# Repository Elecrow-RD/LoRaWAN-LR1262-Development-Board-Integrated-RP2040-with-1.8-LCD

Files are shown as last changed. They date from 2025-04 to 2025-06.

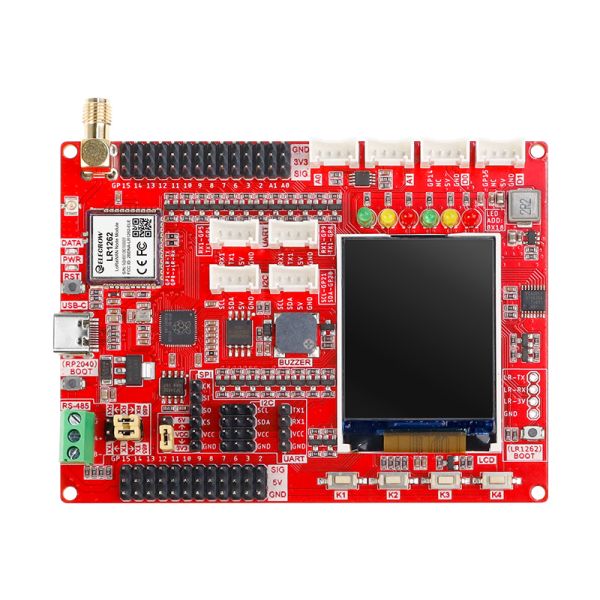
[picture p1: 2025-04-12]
crt01267d_lora_lr1262_dev_board_1.jpg

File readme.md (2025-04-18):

### 1, Product picture

crt01267d_lora_lr1262_dev_board_1

### 2, Product version number

| | Hardware | Software | Remark |
| ---- | --- | --- | --- |
| 1 | V1.0 | V1.0 | latest |

### 3, product information

#### Display Module Specifications

**GPIO Pin Definition**

| RP2040 | LR1262 Development Board | | |
| --- | --- | --- | --- |
| GPIO0  | LR1262-RXD | GPIO15 | GPIO15/ Crowtail-D1 |
| GPIO1  | LR1262-TXD | GPIO16 | LCD-DC |
| GPIO2  | GPIO2 | GPIO17 | LCD-CS |
| GPIO3  | GPIO3 | GPIO18 | LCD-SCK |
| GPIO4  | Crowtail-UART1-TXD | GPIO19 | LCD-DIN |
| GPIO5  | Crowtail-UART1-RXD | GPIO20 | I2C0-SDA0/Crowtail-I2C-SDA/PCA9555-SDA  |
| GPIO6  | GPIO6 | GPIO21 | I2C0-SCL0/Crowtail-I2C-SCL/ PCA9555-SCL |
| GPIO7  | GPIO7 | GPIO22 | LCD-RST |
| GPIO8  | GPIO8/UART1-TX1/Crowtail-UART1-TX1/485TX | GPIO23 | LCD-BLK |
| GPIO9  | GPIO9/UART1-RX1Crowtail-UART1-RX1/485RX  | GPIO24 | 485-EN |
| GPIO10 | GPIO10/SPI1-SCK | GPIO25 | DATA |
| GPIO11 | GPIO11/SPI1-MOSI | GPIO26 | A0/ Crowtail-A0 |
| GPIO12 | GPIO12/SPI1-MISO | GPIO27 | A1/ Crowtail-A1 |
| GPIO13 | GPIO13/SPI1-CS | GPIO28 | BUZZER |
| GPIO14 | GPIO14/ Crowtail-D0 | GPIO29 | ADC-KEY |

## Feature

- Uses RP2040 as the main controller, with two 32-bit ARM Cortex M0+ processor cores (dual-core) ,and provides more powerful performance
- Integrates the LR1262 module supports the 868/915MHz frequency band and AT command control
- Abundant external interface resources, compatible with Crowtail series modules and other commonly interface modules on the market
- Integrates commonly used functionslike buzzer, LED light, LCD display and custom button, making it more concise and convenient when creating projects
- Onboard 1.8-inch 128*160 SPI-TFT-LCD, ST7735S driver chip
- Compatible with Arduino/Micropython, easy to carry out different projects.

## Specification

| Main Chip | Raspberry Pi chip RP2040, built-in 264KB SRAM, onboard 4MB Flash |
| --- | --- |
| Processor | Dual Core Arm Cortex-M0+ @ 133MHz |
| LR1262 Supports frequency band | 803MHZ-930MHZ |
| LR1262 Support Interface | External antenna, SMA interface or IPEX first generation interface |
| LCD Display | Onboard 1.8-inch 128*160SPI-TFT-LCD |
| LCD Resolution | 128*160 |
| LCD Driver | ST7735S (4-wire SPI) |
| Development environment | Arduino/Micropython |
| Interface | 1x RS485 communication interface,8x 5V Crowtail interfaces (2x analog interfaces, 2xdigital interfaces, 2xUART interfaces, 2xIIC interfaces)12x 5V universal pin header IO interfaces14x 3.3V universal pin header IO interfaces1x 3.3V/5V switchable SPI interface1x 3.3V/5V switchable UART interface3x 3.3V/5V switchable IIC interfaces |
| Buttons and functions | 1x passive buzzer,4x user-defined buttons,6x programmable LEDs |
| Working input voltage | USB 5V-1A |
| Operating temperature | -10°C ~ 65°C |
| Dimensions | 102mm(L)x76.5mm(W) |

### 4,Quick Start

##### Arduino IDE starts

STEP1 Configure controller board&communication port
On top of the Arduino IDE, click “Tools>Board>” and select “*Rasperry Pi RP2040 Boards*” from the available options
Lora RA-08H 1 7.png
STEP2 Select the COM port that indicates Rasperry Pi RP2040 Boards. Please note that the actual numbers after the “COM” word will vary from computer to computer, so they could be different from the ones shown in the figure.

### 6,Folder structure.

|--Datasheet: Includes datasheets for components used in the project, providing detailed specifications, electrical characteristics, and pin configurations.

|--Eagle_SCH&PCB: Contains **Eagle CAD** schematic (`.sch`) and PCB layout (`.brd`) files. These are used for circuit design and PCB manufacturing.

|--example: Provides example code and projects to demonstrate how to use the hardware and libraries. These examples help users get started quickly.

|--factory_firmware: Stores pre-compiled factory firmware that can be directly flashed onto the device. This ensures the device runs the default functionality.

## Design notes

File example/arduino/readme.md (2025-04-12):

**Arduino**: This folder contains sample programs for the Arduino platform, which is known for its ease of use and versatility in creating interactive electronic projects.

Link to the corresponding course wiki:

Tutorial Links：https://www.elecrow.com/wiki/lora-ra-08h-development-board.html

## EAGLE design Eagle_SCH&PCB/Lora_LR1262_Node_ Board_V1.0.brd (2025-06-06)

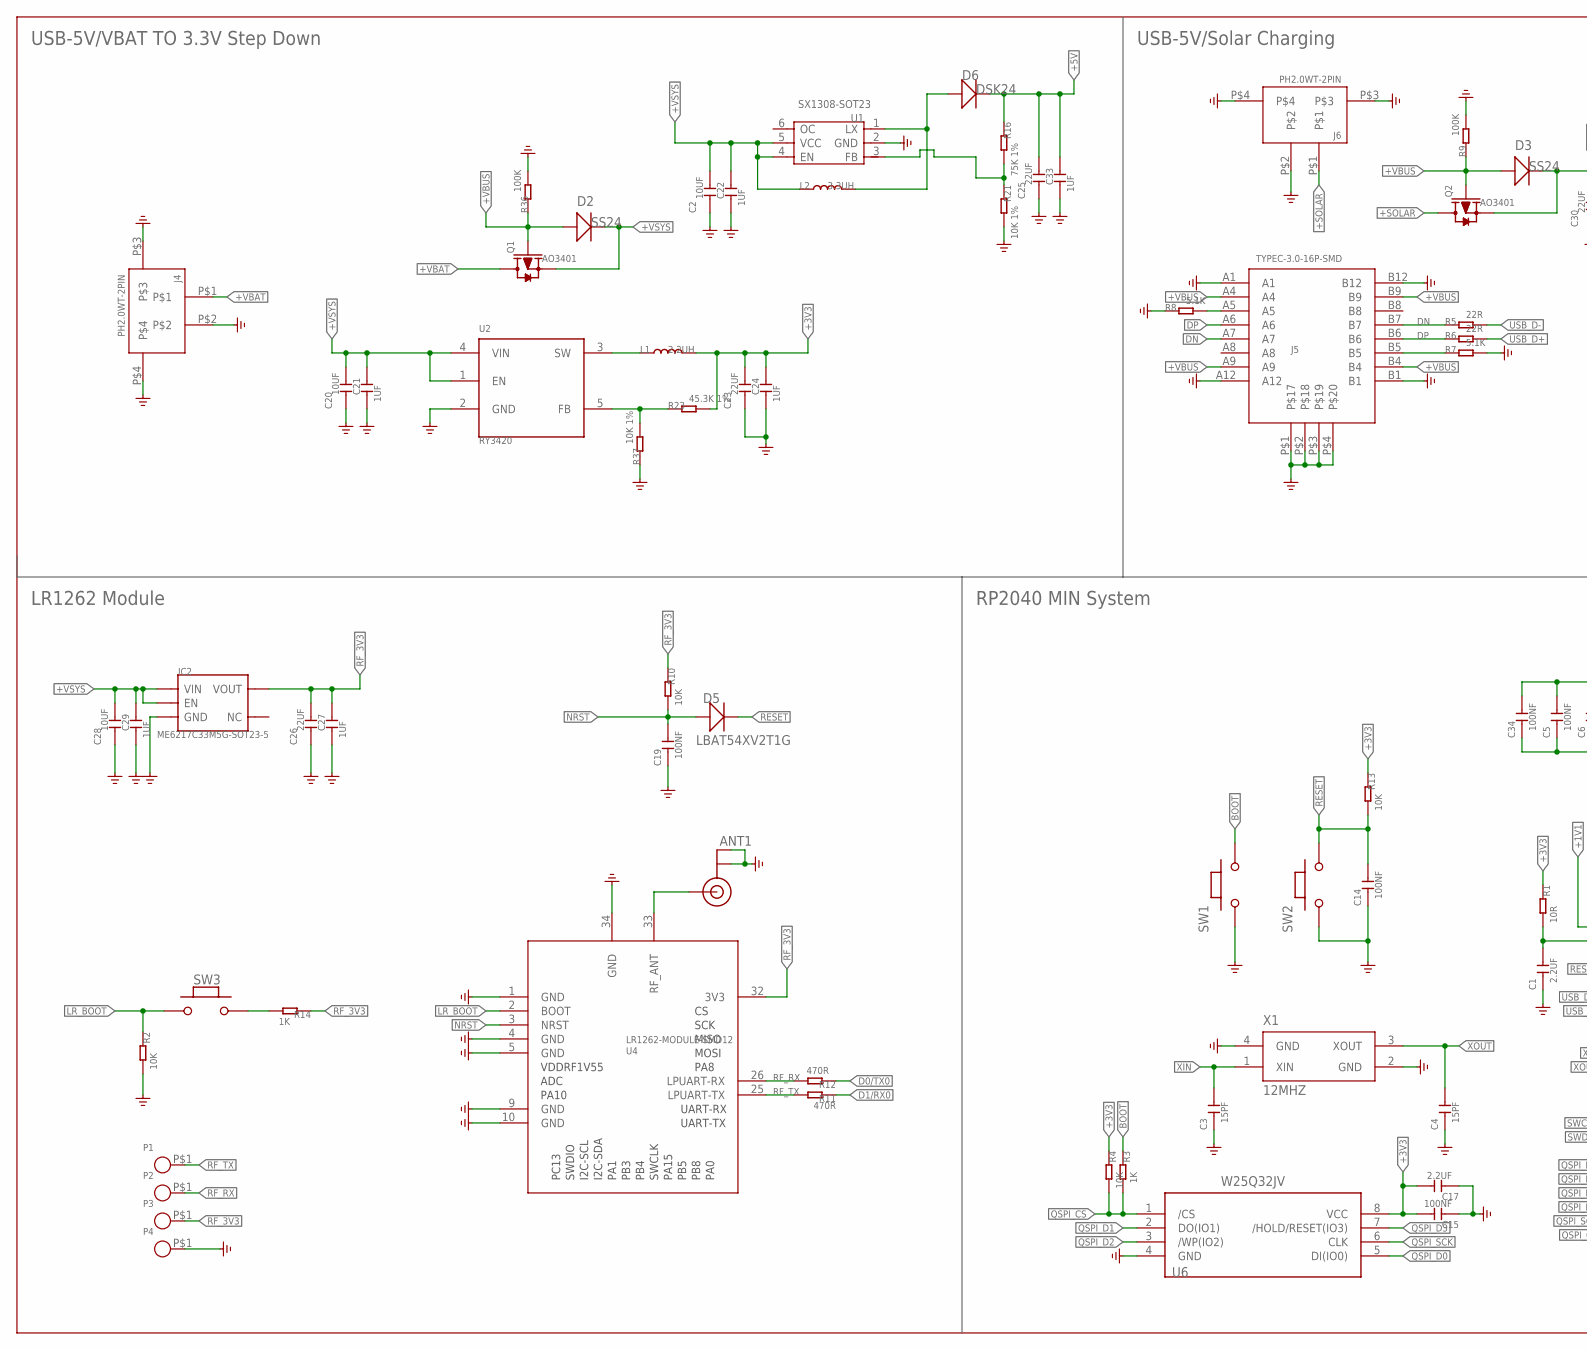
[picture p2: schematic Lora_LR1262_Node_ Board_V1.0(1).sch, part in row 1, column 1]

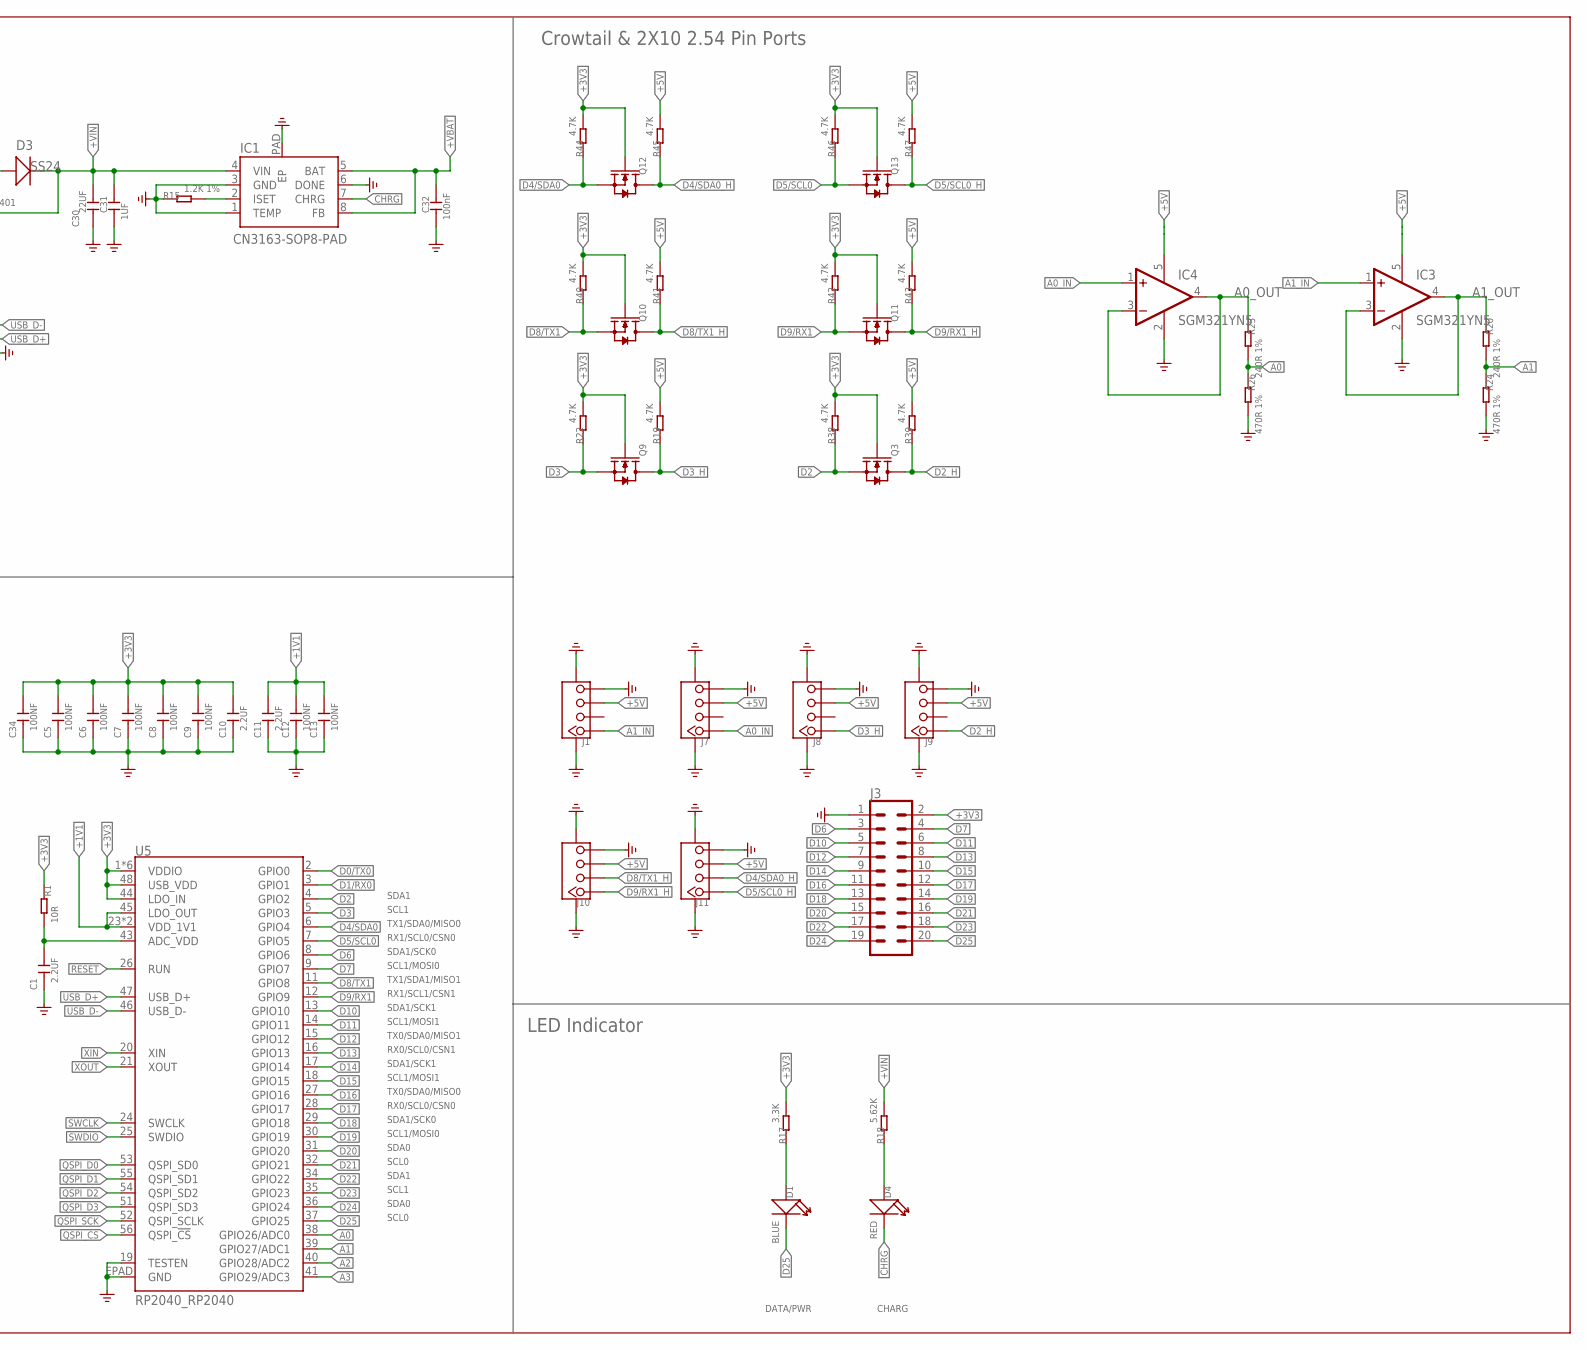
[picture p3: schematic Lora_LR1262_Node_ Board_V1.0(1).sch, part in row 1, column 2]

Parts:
ANT1: SPARKFUN2_U.FL
C1, C10, C11, C17: 2.2UF; 0402
C2, C20, C28: 10UF; C0805
C3, C4: 15PF; 0402
C5, C6, C7, C8, C9, C12, C13, C14, C15, C19, C34: 100NF; 0402
C21, C22, C24, C27, C29, C31, C33: 1UF; C0603
C23, C25, C26, C30: 22UF; C0805
C32: 100nF; C0603
D1: BLUE; LED0603
D2, D3: SS24; SMA
D4: RED; LED0603
D5: LBAT54XV2T1G; D_SOD523
D6: DSK24; D_SOD123FL
IC1: CN3163-SOP8-PAD; SOP8-PAD
IC2: ME6217C33M5G-SOT23-5; IC_SOT23-5
IC3, IC4: SGM321YN5; SOT23-5
J1, J7, J8, J9, J10, J11: CONNECTOR_TWIG-4P-2.0-SMD-FEMALE-REINFORCE90D; CONNECTOR_4P-SMD-2.0-90D
J3: CONN_10X22X10-DSY-P2.54; 2X10-DSY-P2.54
J4, J6: PH2.0WT-2PIN
J5: TYPEC-3.0-16P-SMD; KEVIN_3.0TYPEC-SMD
L1: 2.2UH; L0420
L2: 3.3UH; L0420
P1, P2, P3, P4: TEST_PADPAD-1.5MM; TEST_PAD-1.5MM
Q1, Q2: AO3401; PMOS_SOT23
Q3, Q9, Q10, Q11, Q12, Q13: MOSFET-NSI1304BDL; MOS_SOT323
R1: 10R; R0402
R2, R4, R10, R13: 10K; R0402
R3, R14: 1K; R0402
R5, R6: 22R; R0402
R7, R8: 5.1K; R0402
R9, R36: 100K; R0402
R11, R12: 470R; R0402
R15: 1.2K 1%; R0402
R16: 75K 1%; R0402
R17: 3.3K; R0402
R18: 5.62K; R0402
R19, R22, R38, R39, R40, R41, R42, R43, R44, R45, R46, R47: 4.7K; R0402
R20, R25: 240R 1%; R0402
R21, R37: 10K 1%; R0402
R23: 45.3K 1%; R0402
R24, R26: 470R 1%; R0402
SW1, SW2, SW3: MYSMD_PB157_4.3X3; MYSMD_157SW
U1: SX1308-SOT23; STUDY_SOT23-6L
U2: RY3420; IC_SOT23-5
U4: LR1262-MODULE-SMD12
U5: RP2040_RP2040; RP2040_QFN-56
U6: W25Q32JV; SELF_SOIC-8-208MIL
X1: 12MHZ; SMD3225

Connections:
+1V1: C11.2, C12.2, C13.2, U5.23 (VDD_1V1), U5.45 (LDO_OUT), U5.50 (VDD_1V1)
+3V3: C5.2, C6.2, C7.2, C8.2, C9.2, C10.2, C15.2, C17.2, C23.2, C24.2, C34.2, J3.2, L1.2, Q3.1 (G), Q9.1 (G), Q10.1 (G), Q11.1 (G), Q12.1 (G), Q13.1 (G), R1.1, R4.1, R13.1, R17.2, R22.2, R23.2, R38.2, R40.2, R42.2, R44.2, R46.2, U5.1 (VDDIO), U5.10 (VDDIO), U5.22 (VDDIO), U5.33 (VDDIO), U5.42 (VDDIO), U5.44 (LDO_IN), U5.48 (USB_VDD), U5.49 (VDDIO), U6.8 (VCC)
+5V: C25.2, C33.2, D6.-, IC3.5 (V+), IC4.5 (V+), J1.3, J7.3, J8.3, J9.3, J10.3, J11.3, R16.1, R19.2, R39.2, R41.2, R43.2, R45.2, R47.2
+SOLAR: J6.P$1, Q2.3 (D)
+VBAT: C32.2, IC1.5 (BAT), IC1.8 (FB), J4.P$1, Q1.3 (D)
+VBUS: D2.2 (+), D3.2 (+), J5.A4, J5.A9, J5.B4, J5.B9, Q1.1 (G), Q2.1 (G), R9.1, R36.1
+VIN: C30.2, C31.2, D3.1 (-), IC1.4 (VIN), Q2.2 (S), R18.2
+VSYS: C2.2, C20.2, C21.2, C22.2, C28.2, C29.2, D2.1 (-), IC2.1 (VIN), IC2.3 (EN), L2.1, Q1.2 (S), U1.4 (EN), U1.5 (VCC), U2.1 (EN), U2.4 (VIN)
A0: R25.2, R26.1, U5.38 (GPIO26/ADC0)
A0_IN: IC4.1 (+IN), J7.1
A0_OUT: IC4.3 (-IN), IC4.4 (OUT), R25.1
A1: R20.2, R24.1, U5.39 (GPIO27/ADC1)
A1_IN: IC3.1 (+IN), J1.1
A1_OUT: IC3.3 (-IN), IC3.4 (OUT), R20.1
A2: U5.40 (GPIO28/ADC2)
A3: U5.41 (GPIO29/ADC3)
BOOT: R3.1, SW1.2
CHRG: D4.-, IC1.7 (CHRG)
D0/TX0: R12.1, U5.2 (GPIO0)
D1/RX0: R11.1, U5.3 (GPIO1)
D2: Q3.2 (S), R38.1, U5.4 (GPIO2)
D2_H: J9.1, Q3.3 (D), R39.1
D3: Q9.2 (S), R22.1, U5.5 (GPIO3)
D3_H: J8.1, Q9.3 (D), R19.1
D4/SDA0: Q12.2 (S), R44.1, U5.6 (GPIO4)
D4/SDA0_H: J11.2, Q12.3 (D), R45.1
D5/SCL0: Q13.2 (S), R46.1, U5.7 (GPIO5)
D5/SCL0_H: J11.1, Q13.3 (D), R47.1
D6: J3.3, U5.8 (GPIO6)
D7: J3.4, U5.9 (GPIO7)
D8/TX1: Q10.2 (S), R40.1, U5.11 (GPIO8)
D8/TX1_H: J10.2, Q10.3 (D), R41.1
D9/RX1: Q11.2 (S), R42.1, U5.12 (GPIO9)
D9/RX1_H: J10.1, Q11.3 (D), R43.1
D10: J3.5, U5.13 (GPIO10)
D11: J3.6, U5.14 (GPIO11)
D12: J3.7, U5.15 (GPIO12)
D13: J3.8, U5.16 (GPIO13)
D14: J3.9, U5.17 (GPIO14)
D15: J3.10, U5.18 (GPIO15)
D16: J3.11, U5.27 (GPIO16)
D17: J3.12, U5.28 (GPIO17)
D18: J3.13, U5.29 (GPIO18)
D19: J3.14, U5.30 (GPIO19)
D20: J3.15, U5.31 (GPIO20)
D21: J3.16, U5.32 (GPIO21)
D22: J3.17, U5.34 (GPIO22)
D23: J3.18, U5.35 (GPIO23)
D24: J3.19, U5.36 (GPIO24)
D25: D1.-, J3.20, U5.37 (GPIO25)
DN: J5.A7, J5.B7, R5.1
DP: J5.A6, J5.B6, R6.1
GND: ANT1.P$1 (GND), ANT1.P$2 (GND), C1.1, C2.1, C3.1, C4.1, C5.1, C6.1, C7.1, C8.1, C9.1, C10.1, C11.1, C12.1, C13.1, C14.1, C15.1, C17.1, C19.1, C20.1, C21.1, C22.1, C23.1, C24.1, C25.1, C26.1, C27.1, C28.1, C29.1, C30.1, C31.1, C32.1, C33.1, C34.1, IC1.1 (TEMP), IC1.3 (GND), IC1.6 (DONE), IC1.PAD (EP), IC2.2 (GND), IC3.2 (V-), IC4.2 (V-), J1.4, J1.SS1, J1.SS2, J3.1, J4.P$2, J4.P$3, J4.P$4, J5.A1, J5.A12, J5.B1, J5.B12, J5.P$1, J5.P$2, J5.P$3, J5.P$4, J6.P$2, J6.P$3, J6.P$4, J7.4, J7.SS1, J7.SS2, J8.4, J8.SS1, J8.SS2, J9.4, J9.SS1, J9.SS2, J10.4, J10.SS1, J10.SS2, J11.4, J11.SS1, J11.SS2, P4.P$1, R2.2, R7.2, R8.1, R9.2, R15.1, R21.2, R24.2, R26.2, R36.2, R37.1, SW1.1, SW2.1, U1.2 (GND), U2.2 (GND), U4.1 (GND), U4.4 (GND), U4.5 (GND), U4.9 (GND), U4.10 (GND), U4.34 (GND), U5.19 (TESTEN), U5.EPAD (GND), U6.4 (GND), X1.2 (GND), X1.4 (GND)
LR_BOOT: R2.1, SW3.1, U4.2 (BOOT)
unnamed: C1.2, R1.2, U5.43 (ADC_VDD)
unnamed: J5.B5, R7.1
unnamed: L1.1, U2.3 (SW)
unnamed: D6.+, L2.2, U1.1 (LX)
unnamed: J5.A5, R8.2
unnamed: R14.2, SW3.2
unnamed: ANT1.P$3 (SIGNAL), U4.33 (RF_ANT)
unnamed: R23.1, R37.2, U2.5 (FB)
unnamed: IC1.2 (ISET), R15.2
unnamed: D4.+, R18.1
unnamed: R16.2, R21.1, U1.3 (FB)
unnamed: D1.+, R17.1
NRST: C19.2, D5.+, R10.2, U4.3 (NRST)
QSPI_CS: R3.2, R4.2, U5.56 (QSPI_!CS!), U6.1 (/CS)
QSPI_D0: U5.53 (QSPI_SD0), U6.5 (DI(IO0))
QSPI_D1: U5.55 (QSPI_SD1), U6.2 (DO(IO1))
QSPI_D2: U5.54 (QSPI_SD2), U6.3 (/WP(IO2))
QSPI_D3: U5.51 (QSPI_SD3), U6.7 (/HOLD/RESET(IO3))
QSPI_SCK: U5.52 (QSPI_SCLK), U6.6 (CLK)
RESET: C14.2, D5.-, R13.2, SW2.2, U5.26 (RUN)
RF_3V3: C26.2, C27.2, IC2.5 (VOUT), P3.P$1, R10.1, R14.1, U4.32 (3V3)
RF_RX: P2.P$1, R12.2, U4.26 (LPUART-RX)
RF_TX: P1.P$1, R11.2, U4.25 (LPUART-TX)
SWCLK: U5.24 (SWCLK)
SWDIO: U5.25 (SWDIO)
USB_D+: R6.2, U5.47 (USB_D+)
USB_D-: R5.2, U5.46 (USB_D-)
XIN: C3.2, U5.20 (XIN), X1.1 (XIN)
XOUT: C4.2, U5.21 (XOUT), X1.3 (XOUT)

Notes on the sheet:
USB-5V/VBAT TO 3.3V Step Down
USB-5V/Solar Charging
LR1262 Module
RP2040 MIN System
Crowtail & 2X10 2.54 Pin Ports
LED Indicator
DATA/PWR
CHARG
SDA1
SCL1
TX1/SDA0/MISO0
RX1/SCL0/CSN0
SDA1/SCK0
SCL1/MOSI0
TX1/SDA1/MISO1
RX1/SCL1/CSN1
SDA1/SCK1
SCL1/MOSI1
TX0/SDA0/MISO1
RX0/SCL0/CSN1
TX0/SDA0/MISO0
RX0/SCL0/CSN0
SDA0
SCL0

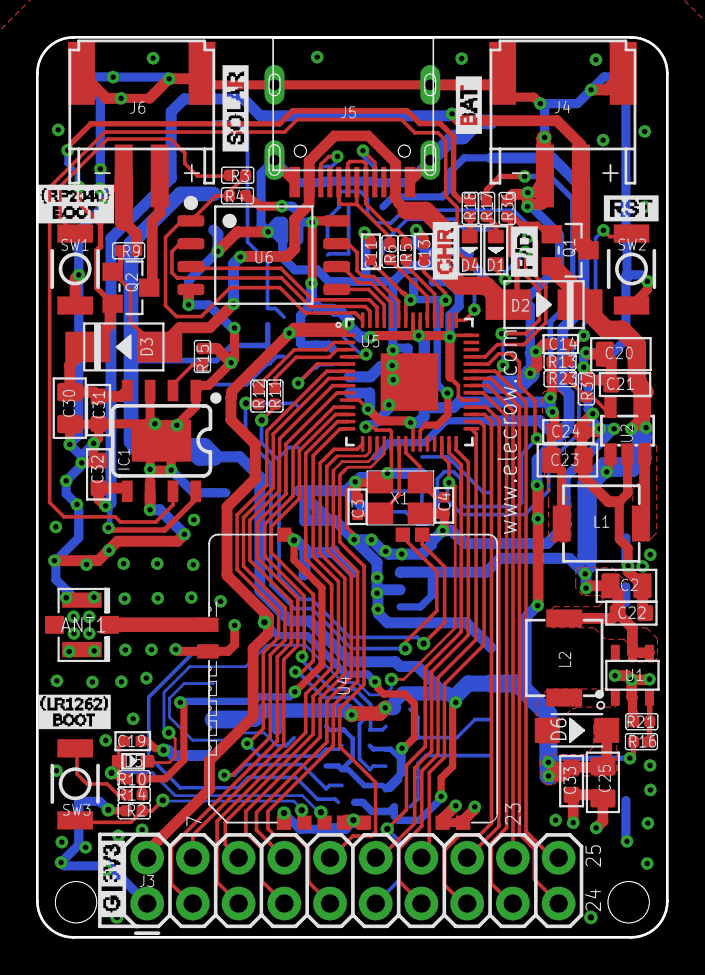
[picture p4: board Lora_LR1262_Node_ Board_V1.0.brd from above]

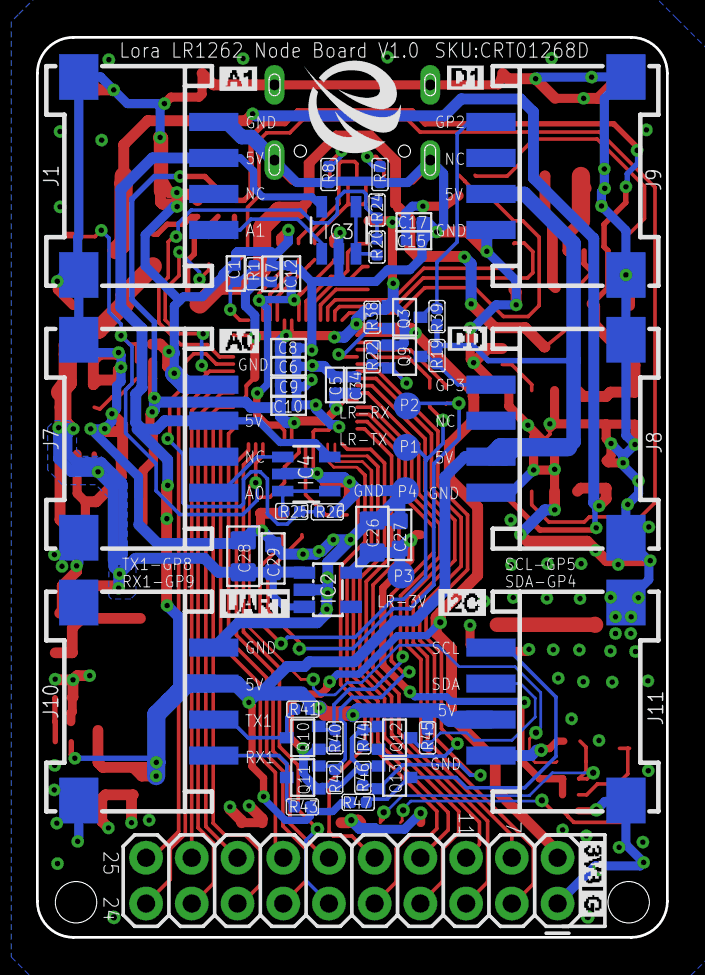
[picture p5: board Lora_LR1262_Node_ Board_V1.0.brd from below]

Board: 2 copper layers, 35.0 x 50.0 mm, 115 parts (54 on the bottom side), 79 nets.

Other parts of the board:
U$55: ELECROW-NEW

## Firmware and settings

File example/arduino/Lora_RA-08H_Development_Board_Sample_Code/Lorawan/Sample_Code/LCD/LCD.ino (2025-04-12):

/*
   Test 128x160 ST7735 SPI TFT Display,
   using TFT_eSPI library
*/

//#include <TFT_eSPI.h>
//#include <SPI.h>
//
//TFT_eSPI tft = TFT_eSPI();
//
//void setup() {
//    tft.init();
//    tft.setRotation(0);
//    //tft.setTextSize(1);
//    tft.fillScreen(TFT_BLACK);
//}
//
//void loop() {
////    tft.setRotation(0);
////    tft.fillScreen(TFT_BLACK);
////
////    tft.drawPixel(10, 10, TFT_WHITE);
////    tft.drawPixel(10, 150, TFT_WHITE);
////    tft.drawPixel(118, 150, TFT_WHITE);
////    tft.drawPixel(118, 10, TFT_WHITE);
////    delay(1000);
////
////    int margin = 10;
////    for(int x=margin; x<=TFT_WIDTH-margin; x++){
////       tft.drawPixel(x, margin, TFT_WHITE);
////       delay(10);
////    }
////    for(int y=margin; y<=TFT_HEIGHT-margin; y++){
////       tft.drawPixel(TFT_WIDTH-margin, y, TFT_WHITE);
////       delay(10);
////    }
////    for(int x=TFT_WIDTH-margin; x>=margin; x--){
////       tft.drawPixel(x, TFT_HEIGHT-margin, TFT_WHITE);
////       delay(10);
////    }
////    for(int y=TFT_HEIGHT-margin; y>=margin; y--){
////       tft.drawPixel(margin, y, TFT_WHITE);
////       delay(10);
////    }
////    delay(500);
////
////    tft.setRotation(1);
////    //tft.fillScreen(TFT_BLACK);
////    tft.setTextColor(TFT_RED, TFT_BLACK);
////    tft.drawString("RED", 10, 10, 4);
////    delay(1000);
////
////    tft.setRotation(2);
////    //tft.fillScreen(TFT_BLACK);
////    tft.setTextColor(TFT_GREEN, TFT_BLACK);
////    tft.drawString("GREEN", 10, 10, 4);
////    delay(1000);
////
////    tft.setRotation(3);
////    //tft.fillScreen(TFT_BLACK);
////    tft.setTextColor(TFT_BLUE, TFT_BLACK);
////    tft.drawString("BLUE", 10, 10, 4);
////    delay(1000);
////
////
////
////    delay(3000);
//}
/**************************************************************************
  This is a library for several Adafruit displays based on ST77* drivers.

  Works with the Adafruit 1.8" TFT Breakout w/SD card
    ----> http://www.adafruit.com/products/358
  The 1.8" TFT shield
    ----> https://www.adafruit.com/product/802
  The 1.44" TFT breakout
    ----> https://www.adafruit.com/product/2088
  The 1.14" TFT breakout
  ----> https://www.adafruit.com/product/4383
  The 1.3" TFT breakout
  ----> https://www.adafruit.com/product/4313
  The 1.54" TFT breakout
    ----> https://www.adafruit.com/product/3787
  The 1.69" TFT breakout
    ----> https://www.adafruit.com/product/5206
  The 2.0" TFT breakout
    ----> https://www.adafruit.com/product/4311
  as well as Adafruit raw 1.8" TFT display
    ----> http://www.adafruit.com/products/618

  Check out the links above for our tutorials and wiring diagrams.
  These displays use SPI to communicate, 4 or 5 pins are required to
  interface (RST is optional).

  Adafruit invests time and resources providing this open source code,
  please support Adafruit and open-source hardware by purchasing
  products from Adafruit!

  Written by Limor Fried/Ladyada for Adafruit Industries.
  MIT license, all text above must be included in any redistribution
 **************************************************************************/

#include <Adafruit_GFX.h>    // Core graphics library
#include <Adafruit_ST7735.h> // Hardware-specific library for ST7735
#include <SPI.h>

#if defined(ARDUINO_FEATHER_ESP32) // Feather Huzzah32
#define TFT_CS         14
#define TFT_RST        15
#define TFT_DC         32

#elif defined(ESP8266)
#define TFT_CS         4
#define TFT_RST        16
#define TFT_DC         5

#else
// For the breakout board, you can use any 2 or 3 pins.
// These pins will also work for the 1.8" TFT shield.
#define TFT_CS        17
#define TFT_RST        22 // Or set to -1 and connect to Arduino RESET pin
#define TFT_DC         16
#endif

// OPTION 1 (recommended) is to use the HARDWARE SPI pins, which are unique
// to each board and not reassignable. For Arduino Uno: MOSI = pin 11 and
// SCLK = pin 13. This is the fastest mode of operation and is required if
// using the breakout board's microSD card.

// For 1.44" and 1.8" TFT with ST7735 use:
//Adafruit_ST7735 tft = Adafruit_ST7735(TFT_CS, TFT_DC, TFT_RST);

// For 1.14", 1.3", 1.54", 1.69", and 2.0" TFT with ST7789:
//Adafruit_ST7789 tft = Adafruit_ST7789(TFT_CS, TFT_DC, TFT_RST);


// OPTION 2 lets you interface the display using ANY TWO or THREE PINS,
// tradeoff being that performance is not as fast as hardware SPI above.
#define TFT_MOSI 19   // Data out
#define TFT_SCLK 18  // Clock out
#define TFT_BL 23
// For ST7735-based displays, we will use this call
Adafruit_ST7735 tft = Adafruit_ST7735(TFT_CS, TFT_DC, TFT_MOSI, TFT_SCLK, TFT_RST);

// OR for the ST7789-based displays, we will use this call
//Adafruit_ST7789 tft = Adafruit_ST7789(TFT_CS, TFT_DC, TFT_MOSI, TFT_SCLK, TFT_RST);


float p = 3.1415926;

void setup(void) {
  Serial.begin(9600);
  Serial.print(F("Hello! ST77xx TFT Test"));
  pinMode(TFT_BL, OUTPUT);

  // Use this initializer if using a 1.8" TFT screen:
  //tft.initR(INITR_BLACKTAB);      // Init ST7735S chip, black tab

  // OR use this initializer if using a 1.8" TFT screen with offset such as WaveShare:
   tft.initR(INITR_GREENTAB);      // Init ST7735S chip, green tab

  // OR use this initializer (uncomment) if using a 1.44" TFT:
  //tft.initR(INITR_144GREENTAB); // Init ST7735R chip, green tab

  // OR use this initializer (uncomment) if using a 0.96" 160x80 TFT:
  //tft.initR(INITR_MINI160x80);  // Init ST7735S mini display

  // OR use this initializer (uncomment) if using a 1.3" or 1.54" 240x240 TFT:
  //tft.init(240, 240);           // Init ST7789 240x240

  // OR use this initializer (uncomment) if using a 1.69" 280x240 TFT:
  //tft.init(240, 280);           // Init ST7789 280x240

  // OR use this initializer (uncomment) if using a 2.0" 320x240 TFT:
 // tft.init(240, 320);           // Init ST7789 320x240

  // OR use this initializer (uncomment) if using a 1.14" 240x135 TFT:
  //tft.init(135, 240);           // Init ST7789 240x135

  // SPI speed defaults to SPI_DEFAULT_FREQ defined in the library, you can override it here
  // Note that speed allowable depends on chip and quality of wiring, if you go too fast, you
  // may end up with a black screen some times, or all the time.
  //tft.setSPISpeed(40000000);

  Serial.println(F("Initialized"));

//  uint16_t time = millis();
//  tft.fillScreen(ST77XX_BLACK);
//  time = millis() - time;
//
//  Serial.println(time, DEC);
//  delay(500);
//
//  // large block of text
//  tft.fillScreen(ST77XX_BLACK);
//  testdrawtext("Lorem ipsum dolor sit amet, consectetur adipiscing elit. Curabitur adipiscing ante sed nibh tincidunt feugiat. Maecenas enim massa, fringilla sed malesuada et, malesuada sit amet turpis. Sed porttitor neque ut ante pretium vitae malesuada nunc bibendum. Nullam aliquet ultrices massa eu hendrerit. Ut sed nisi lorem. In vestibulum purus a tortor imperdiet posuere. ", ST77XX_WHITE);
//  delay(1000);
//
//  // tft print function!
//  tftPrintTest();
//  delay(4000);
//
//  // a single pixel
//  tft.drawPixel(tft.width() / 2, tft.height() / 2, ST77XX_GREEN);
//  delay(500);
//
//  // line draw test
//  testlines(ST77XX_YELLOW);
//  delay(500);
//
//  // optimized lines
//  testfastlines(ST77XX_RED, ST77XX_BLUE);
//  delay(500);
//
//  testdrawrects(ST77XX_GREEN);
//  delay(500);
//
//  testfillrects(ST77XX_YELLOW, ST77XX_MAGENTA);
//  delay(500);
//
//  tft.fillScreen(ST77XX_BLACK);
//  testfillcircles(10, ST77XX_BLUE);
//  testdrawcircles(10, ST77XX_WHITE);
//  delay(500);
//
//  testroundrects();
//  delay(500);
//
//  testtriangles();
//  delay(500);
//
//  mediabuttons();
//  delay(500);
//
//  Serial.println("done");
//  delay(1000);
}

void loop() {
  digitalWrite(TFT_BL, HIGH);
  delay(2000);
  tft.fillScreen(ST77XX_RED);
  delay(2000);
  tft.fillScreen(ST77XX_GREEN);
  delay(2000);
  tft.fillScreen(ST77XX_BLUE);
  delay(2000);
//  tft.invertDisplay(true);
//  delay(500);
//  tft.invertDisplay(false);
//  delay(500);
}

void testlines(uint16_t color) {
  tft.fillScreen(ST77XX_BLACK);
  for (int16_t x = 0; x < tft.width(); x += 6) {
    tft.drawLine(0, 0, x, tft.height() - 1, color);
    delay(0);
  }
  for (int16_t y = 0; y < tft.height(); y += 6) {
    tft.drawLine(0, 0, tft.width() - 1, y, color);
    delay(0);
  }

  tft.fillScreen(ST77XX_BLACK);
  for (int16_t x = 0; x < tft.width(); x += 6) {
    tft.drawLine(tft.width() - 1, 0, x, tft.height() - 1, color);
    delay(0);
  }
  for (int16_t y = 0; y < tft.height(); y += 6) {
    tft.drawLine(tft.width() - 1, 0, 0, y, color);
    delay(0);
  }

  tft.fillScreen(ST77XX_BLACK);
  for (int16_t x = 0; x < tft.width(); x += 6) {
    tft.drawLine(0, tft.height() - 1, x, 0, color);
    delay(0);
  }
  for (int16_t y = 0; y < tft.height(); y += 6) {
    tft.drawLine(0, tft.height() - 1, tft.width() - 1, y, color);
    delay(0);
  }

  tft.fillScreen(ST77XX_BLACK);
  for (int16_t x = 0; x < tft.width(); x += 6) {
    tft.drawLine(tft.width() - 1, tft.height() - 1, x, 0, color);
    delay(0);
  }
  for (int16_t y = 0; y < tft.height(); y += 6) {
    tft.drawLine(tft.width() - 1, tft.height() - 1, 0, y, color);
    delay(0);
  }
}

void testdrawtext(char *text, uint16_t color) {
  tft.setCursor(0, 0);
  tft.setTextColor(color);
  tft.setTextWrap(true);
  tft.print(text);
}

void testfastlines(uint16_t color1, uint16_t color2) {
  tft.fillScreen(ST77XX_BLACK);
  for (int16_t y = 0; y < tft.height(); y += 5) {
    tft.drawFastHLine(0, y, tft.width(), color1);
  }
  for (int16_t x = 0; x < tft.width(); x += 5) {
    tft.drawFastVLine(x, 0, tft.height(), color2);
  }
}

void testdrawrects(uint16_t color) {
  tft.fillScreen(ST77XX_BLACK);
  for (int16_t x = 0; x < tft.width(); x += 6) {
    tft.drawRect(tft.width() / 2 - x / 2, tft.height() / 2 - x / 2 , x, x, color);
  }
}

void testfillrects(uint16_t color1, uint16_t color2) {
  tft.fillScreen(ST77XX_BLACK);
  for (int16_t x = tft.width() - 1; x > 6; x -= 6) {
    tft.fillRect(tft.width() / 2 - x / 2, tft.height() / 2 - x / 2 , x, x, color1);
    tft.drawRect(tft.width() / 2 - x / 2, tft.height() / 2 - x / 2 , x, x, color2);
  }
}

void testfillcircles(uint8_t radius, uint16_t color) {
  for (int16_t x = radius; x < tft.width(); x += radius * 2) {
    for (int16_t y = radius; y < tft.height(); y += radius * 2) {
      tft.fillCircle(x, y, radius, color);
    }
  }
}

void testdrawcircles(uint8_t radius, uint16_t color) {
  for (int16_t x = 0; x < tft.width() + radius; x += radius * 2) {
    for (int16_t y = 0; y < tft.height() + radius; y += radius * 2) {
      tft.drawCircle(x, y, radius, color);
    }
  }
}

void testtriangles() {
  tft.fillScreen(ST77XX_BLACK);
  uint16_t color = 0xF800;
  int t;
  int w = tft.width() / 2;
  int x = tft.height() - 1;
  int y = 0;
  int z = tft.width();
  for (t = 0 ; t <= 15; t++) {
    tft.drawTriangle(w, y, y, x, z, x, color);
    x -= 4;
    y += 4;
    z -= 4;
    color += 100;
  }
}

void testroundrects() {
  tft.fillScreen(ST77XX_BLACK);
  uint16_t color = 100;
  int i;
  int t;
  for (t = 0 ; t <= 4; t += 1) {
    int x = 0;
    int y = 0;
    int w = tft.width() - 2;
    int h = tft.height() - 2;
    for (i = 0 ; i <= 16; i += 1) {
      tft.drawRoundRect(x, y, w, h, 5, color);
      x += 2;
      y += 3;
      w -= 4;
      h -= 6;
      color += 1100;
    }
    color += 100;
  }
}

void tftPrintTest() {
  tft.setTextWrap(false);
  tft.fillScreen(ST77XX_BLACK);
  tft.setCursor(0, 30);
  tft.setTextColor(ST77XX_RED);
  tft.setTextSize(1);
  tft.println("Hello World!");
  tft.setTextColor(ST77XX_YELLOW);
  tft.setTextSize(2);
  tft.println("Hello World!");
  tft.setTextColor(ST77XX_GREEN);
  tft.setTextSize(3);
  tft.println("Hello World!");
  tft.setTextColor(ST77XX_BLUE);
  tft.setTextSize(4);
  tft.print(1234.567);
  delay(1500);
  tft.setCursor(0, 0);
  tft.fillScreen(ST77XX_BLACK);
  tft.setTextColor(ST77XX_WHITE);
  tft.setTextSize(0);
  tft.println("Hello World!");
  tft.setTextSize(1);
  tft.setTextColor(ST77XX_GREEN);
  tft.print(p, 6);
  tft.println(" Want pi?");
  tft.println(" ");
  tft.print(8675309, HEX); // print 8,675,309 out in HEX!
  tft.println(" Print HEX!");
  tft.println(" ");
  tft.setTextColor(ST77XX_WHITE);
  tft.println("Sketch has been");
  tft.println("running for: ");
  tft.setTextColor(ST77XX_MAGENTA);
  tft.print(millis() / 1000);
  tft.setTextColor(ST77XX_WHITE);
  tft.print(" seconds.");
}

void mediabuttons() {
  // play
  tft.fillScreen(ST77XX_BLACK);
  tft.fillRoundRect(25, 10, 78, 60, 8, ST77XX_WHITE);
  tft.fillTriangle(42, 20, 42, 60, 90, 40, ST77XX_RED);
  delay(500);
  // pause
  tft.fillRoundRect(25, 90, 78, 60, 8, ST77XX_WHITE);
  tft.fillRoundRect(39, 98, 20, 45, 5, ST77XX_GREEN);
  tft.fillRoundRect(69, 98, 20, 45, 5, ST77XX_GREEN);
  delay(500);
  // play color
  tft.fillTriangle(42, 20, 42, 60, 90, 40, ST77XX_BLUE);
  delay(50);
  // pause color
  tft.fillRoundRect(39, 98, 20, 45, 5, ST77XX_RED);
  tft.fillRoundRect(69, 98, 20, 45, 5, ST77XX_RED);
  // play color
  tft.fillTriangle(42, 20, 42, 60, 90, 40, ST77XX_GREEN);
}

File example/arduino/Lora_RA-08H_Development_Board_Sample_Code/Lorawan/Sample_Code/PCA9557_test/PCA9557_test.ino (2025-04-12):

//#include <Arduino.h>
//#include <Wire.h>
//#include <PCA9557.h>
//#define PCA9557_I2C_SLAVE_ADDR  0x18
//#define SDA 20
//#define SCL 21
//#define PCA9557_DEBUG
//PCA9557 io(PCA9557_I2C_SLAVE_ADDR, &Wire);
//
//// Relay output pin
//#define RED1_PIN (2)
//#define YEL1_PIN (3)
//#define GRE1_PIN (4)
//#define RED2_PIN (5)
//#define YEL2_PIN (6)
//#define GRE2_PIN (7)
//
//
//void setup() {
//  Serial.begin(115200);
//  Wire.setSDA(SDA);
//  Wire.setSCL(SCL);
//  Wire.begin();
//  io.pinMode(0, OUTPUT);
//  io.pinMode(1, OUTPUT);
//  io.pinMode(RED1_PIN, OUTPUT);
//  io.pinMode(YEL1_PIN, OUTPUT);
//  io.pinMode(GRE1_PIN, OUTPUT);
//  io.pinMode(RED2_PIN, OUTPUT);
//  io.pinMode(YEL2_PIN, OUTPUT);
//  io.pinMode(GRE2_PIN, OUTPUT);
//}
//
//void loop() {
//  io.digitalWrite(0, HIGH);
//  io.digitalWrite(1, HIGH);
//  io.digitalWrite(RED1_PIN, HIGH);
//  io.digitalWrite(YEL1_PIN, HIGH);
//  io.digitalWrite(GRE1_PIN, HIGH);
//  io.digitalWrite(RED2_PIN, HIGH);
//  io.digitalWrite(YEL2_PIN, HIGH);
//  io.digitalWrite(GRE2_PIN, HIGH);
//  Serial.println("off");
//  delay(1000);
//  io.digitalWrite(0, LOW);
//  io.digitalWrite(1, LOW);
//  io.digitalWrite(RED1_PIN, LOW);
//  io.digitalWrite(YEL1_PIN, LOW);
//  io.digitalWrite(GRE1_PIN, LOW);
//  io.digitalWrite(RED2_PIN, LOW);
//  io.digitalWrite(YEL2_PIN, LOW);
//  io.digitalWrite(GRE2_PIN, LOW);
//  Serial.println("on");
//  delay(1000);
//
//}

#include <Arduino.h>
#include <Wire.h>
#include <PCA9557.h>

#define SDA 20
#define SCL 21

PCA9557 Out;
int LED = 25;
void setup() {
  Serial.begin(115200);
  Wire.setSDA(SDA);
  Wire.setSCL(SCL);
  Wire.begin();
  Out.reset();
  Out.setMode(IO_OUTPUT);
  pinMode(LED, OUTPUT);
}

void loop() {
//  Out.setState(IO2, IO_HIGH);
//  Out.setState(IO3, IO_HIGH);
//  Out.setState(IO4, IO_HIGH);
//  Out.setState(IO5, IO_HIGH);
//  Out.setState(IO6, IO_HIGH);
//  Out.setState(IO7, IO_HIGH);
//  Serial.println("off");
//  delay(1000);
  Out.setState(IO2, IO_LOW);
  Out.setState(IO3, IO_LOW);
  Out.setState(IO4, IO_LOW);
  Out.setState(IO5, IO_LOW);
  Out.setState(IO6, IO_LOW);
  Out.setState(IO7, IO_LOW);
  digitalWrite(LED_BUILTIN, LOW);
  Serial.println("on");
  delay(1000);
  

}
